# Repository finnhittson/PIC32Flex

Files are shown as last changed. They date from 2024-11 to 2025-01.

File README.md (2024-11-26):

# PIC32Flex 

PIC32Flex is a breakout board for the PIC32MX170F256B. This repo holds schematic revision information, how to fabricate this board for yourself, and examples on how to use the board. I designed this board for rapid prototyping, testing, and better wire management for projects and circuits that use the PIC32 as a microcontroller. Specifically, I made PIC32Flex for Stanford's ME218 mechatronics course sequence which exclusively uses the PIC32 as the microcontroller for all student projects. For this reason, it is wired to interface directly with the [MPLAB Snap](https://www.microchip.com/en-us/development-tool/pg164100) and the [CP2102 debugger](https://www.silabs.com/interface/usb-bridges/classic/device.cp2102?tab=specs).

<p align="center">
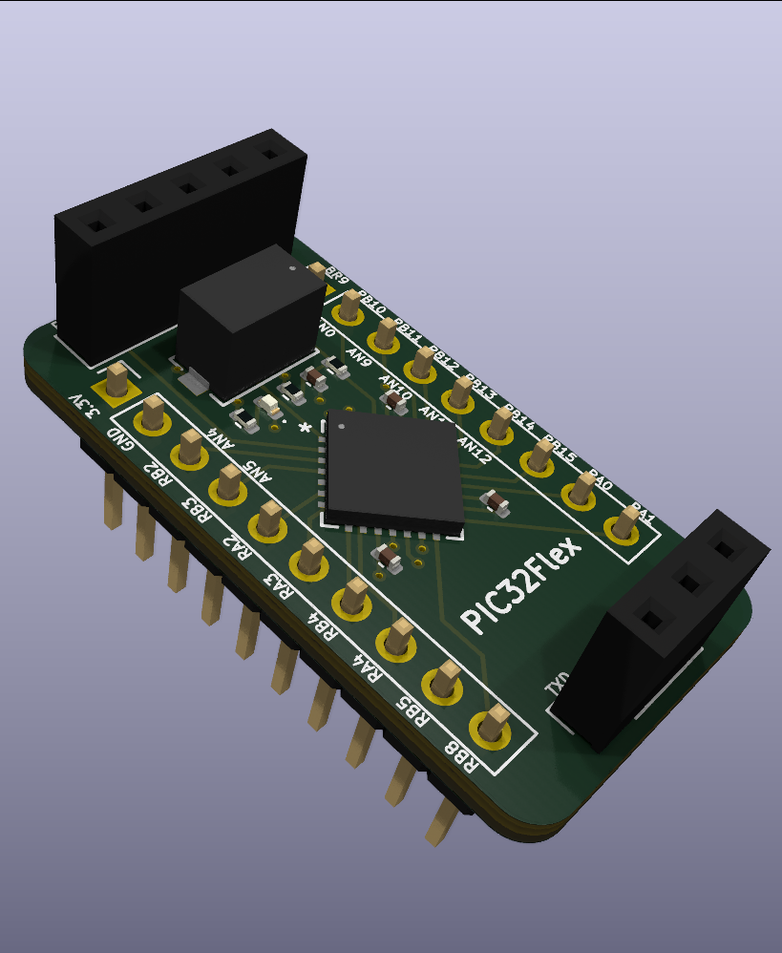
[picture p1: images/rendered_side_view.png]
  
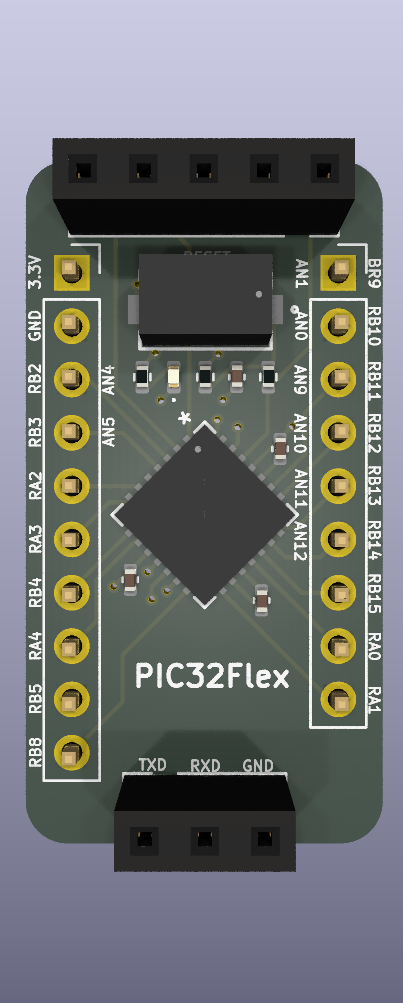
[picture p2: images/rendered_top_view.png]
  
</p>

## Download and Modification

To modify or view a revision of PIC32Flex, download any version of the board from the `hardware/` directory. All revisions were made using [KiCad 8.0](https://www.kicad.org/download/) which is a free PCB design software. Once downloaded, extract the file into the directory of your choice and open the `PIC32Flex.kicad_pro` file. This should open up a the KiCad start page where you can choose to view and then modify the schematic, PCB layout, and most other features related to the board. KiCad files are not backwards compatible so you may need to upgrade to KiCad 8.0 if you are working with an older version. If you download the most recent version and open the schematic editor, you will find the following.

<p align="center">
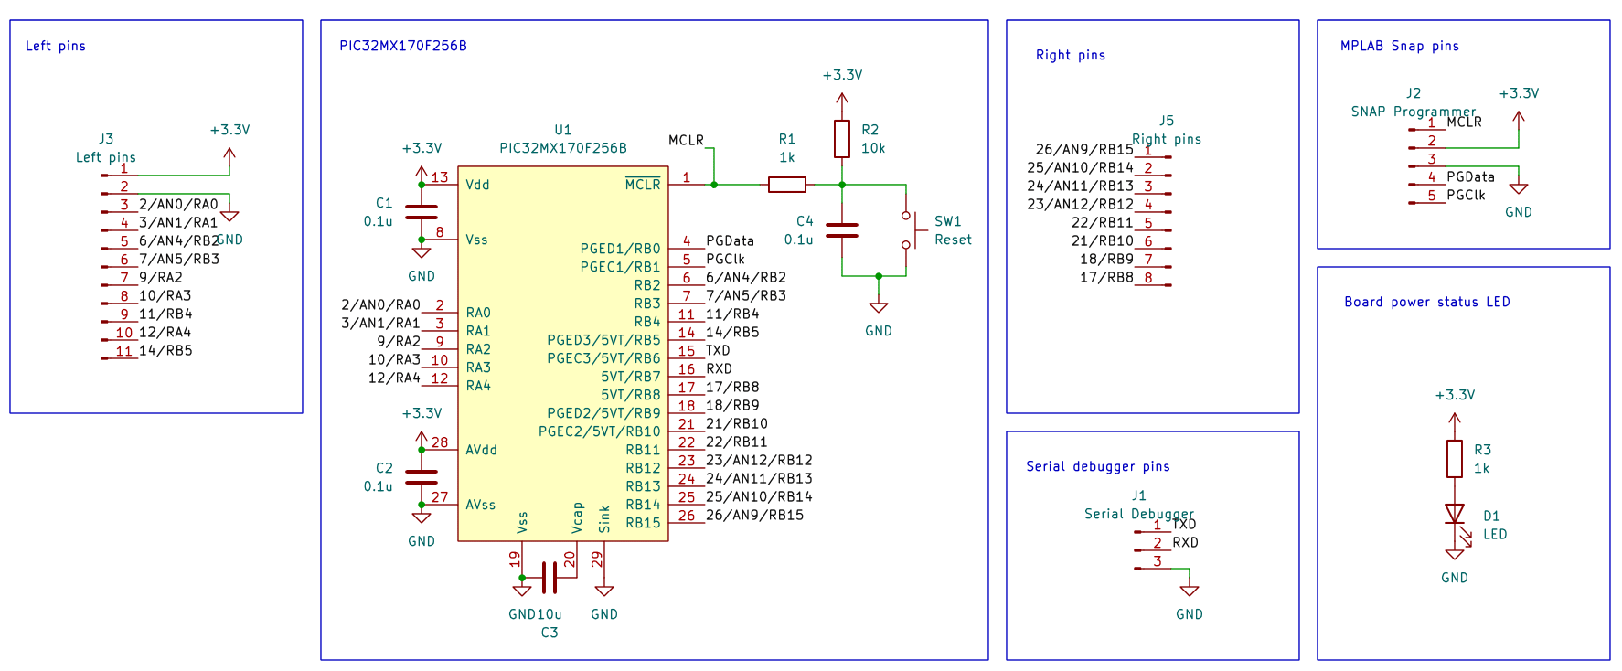
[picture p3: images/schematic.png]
  
</p>

Opening the PCB editor of the latest version should present the following PCB layout.

<p align="center">
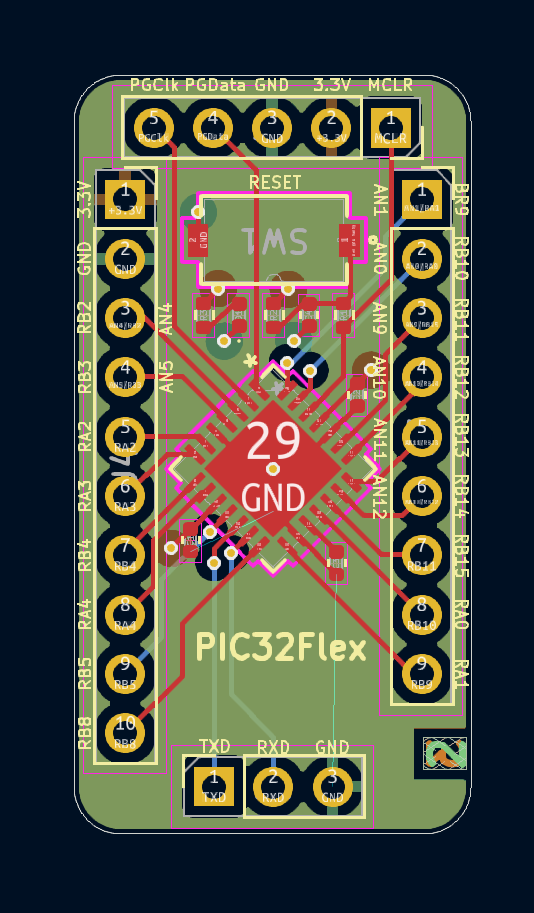
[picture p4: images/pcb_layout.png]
  
</p>

## Usage

To build this board for yourself you need to send the gerber files to a PCB manufacturer. Most used are [JLCPCN](https://jlcpcb.com/) and [PCBWay](https://www.pcbway.com/). After unzipping the downloaded board file, upload the `gerber.zip` file to a PCB manufacturer of your choice. It is recommended that the PIC32Flex is reflowed and not hand soldered. For this reason, be sure to include a stencil in your board purchase since they are not included by default. Board lead time is typically longer than a week. With the board ordered you will also need to order components for board population. Components can be ordered from [DigiKey](digikey.com) or [Mouser](mouser.com). With either of these suppliers you can upload the bill of materials file, `bom.csv`, and it will usually parse and place all the items in the cart. Below is a cost breakdown for the devices necessary for board population.

<div align="center">

| Qty | Reference | Value | Mfn | Mfn PN | Cost ($/device) |
|-----|---|---|---|---|---|
| 1 | C3 | 10u | Murata Electronics | GRM155R60J106ME05D | $0.10  |
| 3 | C1, C2, C4  | 0.1u | Murata Electronics | GRM155R71C104KA88J | $0.08  |
| 1 | D1 | LED | Inolux | IN-S42BTR | $0.28  |
| 1 | R2 | 10k | YAGEO | RC0402JR-0710KL | $0.10  |
| 2 | R1, R3 | 1k | YAGEO | RC0402JR-071KL | $0.10  |
| 1 | SW1 | Reset | C&K | PTS636SM50JSMTR LFS | $0.25  |
| 1 | U1 | PIC32MX170F256B | Microchip Technology | PIC32MX170F256B-I/ML | $4.86  |
| | | | | Total Device Cost | $6.03  |
| | | | | Total Board Cost w/ stencil | $9.11  |
| | | | | Total Costs | $15.14 |

</div>

This cost analysis does not include sales tax and shipping. These costs usually eclipse the cost of the board and components themselves, if you plan to only make a few.

## Contributing

Please download and change. Explore and learn. Please feel free to contact with questions, suggestions, and other projects you would like to see.

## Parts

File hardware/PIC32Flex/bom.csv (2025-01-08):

Qty | Reference | Value | Datasheet | Footprint | DNP | Mfn | Mfn PN | Supplier | Supplier PN
1 | C3 | 10u | https://search.murata.co.jp/Ceramy/image/img/A01X/G101/ENG/GRM155R60J106ME05-01A.pdf | Capacitor_SMD:C_0402_1005Metric |  | Murata Electronics | GRM155R60J106ME05D | DigiKey | 490-GRM155R60J106ME05DTR-ND
3 | C1,C2,C4 | 0.1u | https://search.murata.co.jp/Ceramy/image/img/A01X/G101/ENG/GRM155R71C104KA88-01.pdf | Capacitor_SMD:C_0402_1005Metric |  | Murata Electronics | GRM155R71C104KA88J | DigiKey | 490-6328-2-ND
1 | D1 | LED | https://www.inolux-corp.com/datasheet/SMDLED/Mono%20Color%20Top%20View/IN-S42BT%20Series_V1.0.pdf | LED_SMD:LED_0402_1005Metric |  | Inolux | IN-S42BTR | DigiKey | 1830-IN-S42BTR-ND
1 | J1 | Serial Debugger | ~ | Connector_PinSocket_2.54mm:PinSocket_1x03_P2.54mm_Vertical
1 | J2 | SNAP Programmer | ~ | Connector_PinSocket_2.54mm:PinSocket_1x05_P2.54mm_Vertical
1 | J3 | Conn_01x11_Pin | ~ | Connector_PinSocket_2.54mm:PinSocket_1x11_P2.54mm_Vertical
1 | J5 | Conn_01x08_Pin | ~ | Connector_PinHeader_2.54mm:PinHeader_1x08_P2.54mm_Vertical
1 | R2 | 10k | https://www.yageo.com/upload/media/product/products/datasheet/rchip/PYu-RC_Group_51_RoHS_L_12.pdf | Resistor_SMD:R_0402_1005Metric |  | YAGEO | RC0402JR-0710KL | DigiKey | 311-10KJRTR-ND
2 | R1,R3 | 1k | https://www.yageo.com/upload/media/product/products/datasheet/rchip/PYu-RC_Group_51_RoHS_L_12.pdf | Resistor_SMD:R_0402_1005Metric |  | YAGEO | RC0402JR-071KL | DigiKey | 311-1.0KJRTR-ND
1 | SW1 | Reset | https://www.ckswitches.com/media/2779/pts636.pdf | pic32_breakout:SW_PTS636_CNK |  | C&K | PTS636SM50JSMTR LFS | DigiKey | CKN12319-2-ND
1 | U1 | PIC32MX170F256B | https://www.digikey.com/en/models/4902616 | pic32_breakout:QFN28_6X6MC_MCH |  | Microchip Technology | PIC32MX170F256B-I/ML | DigiKey | PIC32MX170F256B-I/ML-ND

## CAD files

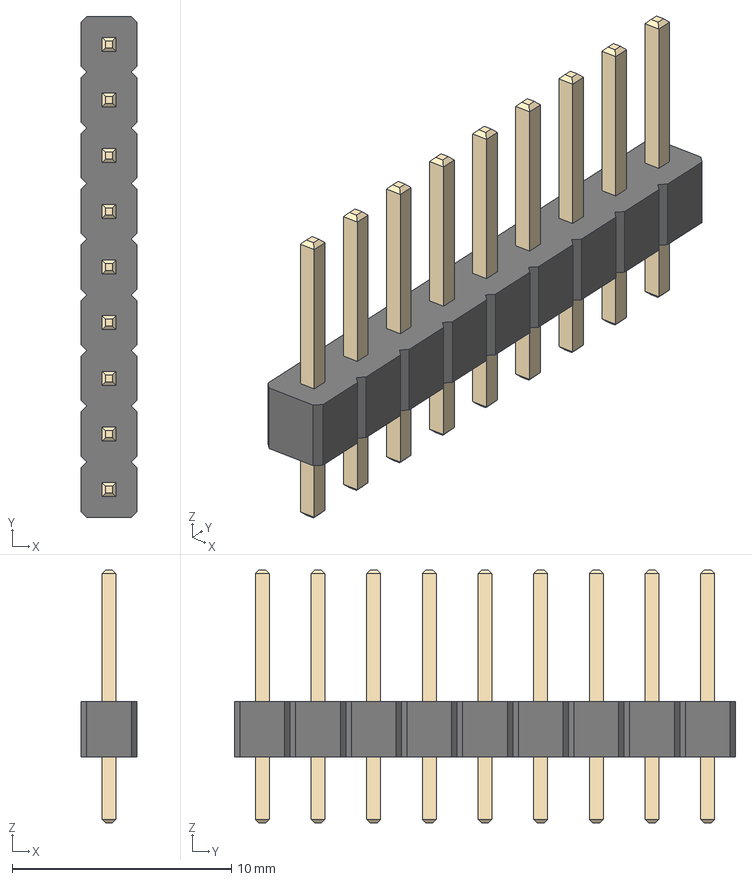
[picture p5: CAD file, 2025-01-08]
hardware/PIC32Flex/3d_models/PinHeader_1x09_P2.54mm_Vertical.step
2.54 x 22.9 x 11.5 mm

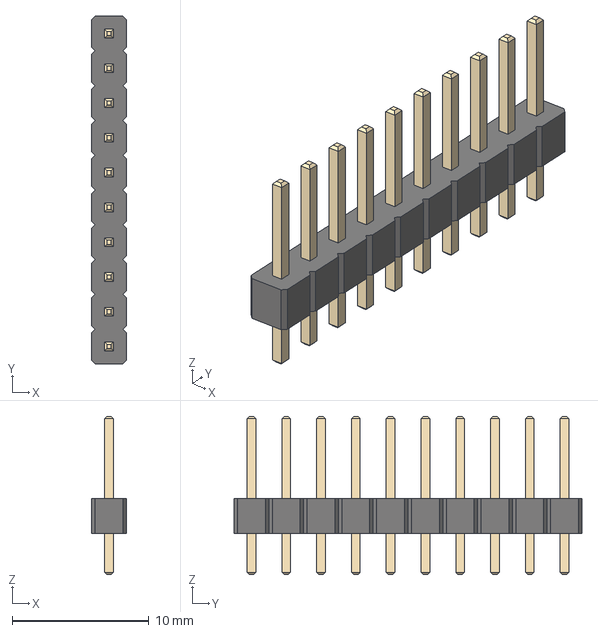
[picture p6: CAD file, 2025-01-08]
hardware/PIC32Flex/3d_models/PinHeader_1x10_P2.54mm_Vertical.step
2.54 x 25.4 x 11.5 mm

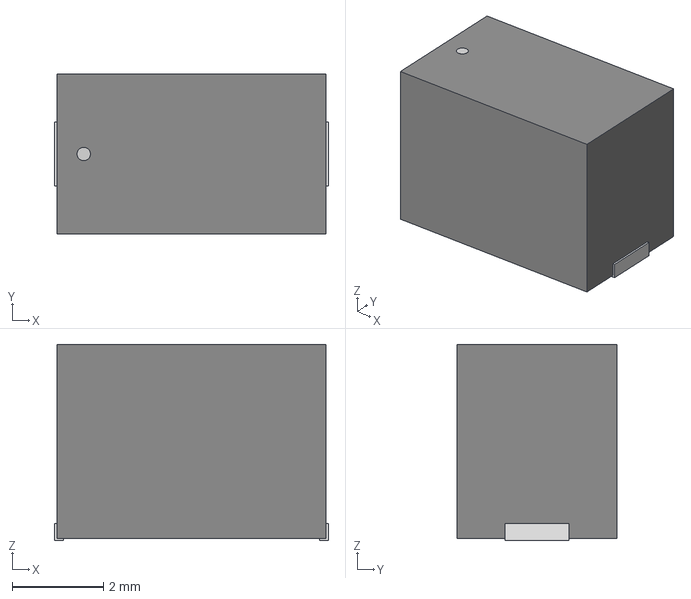
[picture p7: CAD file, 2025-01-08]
hardware/PIC32Flex/3d_models/SW_PTS636_CNK.step
5.99 x 3.51 x 4.29 mm

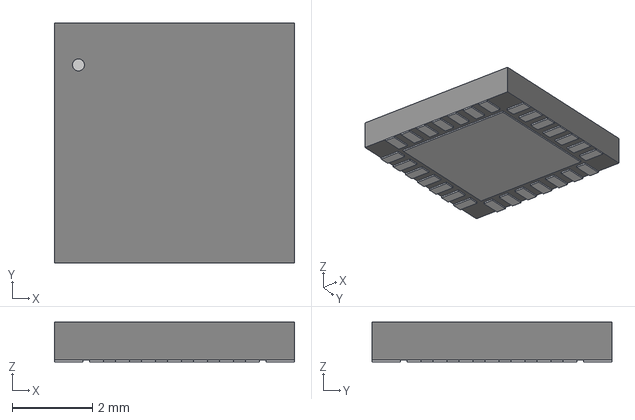
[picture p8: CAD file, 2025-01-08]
hardware/PIC32Flex/3d_models/QFN28_6X6MC_MCH.step
5.99 x 5.99 x 0.993 mm

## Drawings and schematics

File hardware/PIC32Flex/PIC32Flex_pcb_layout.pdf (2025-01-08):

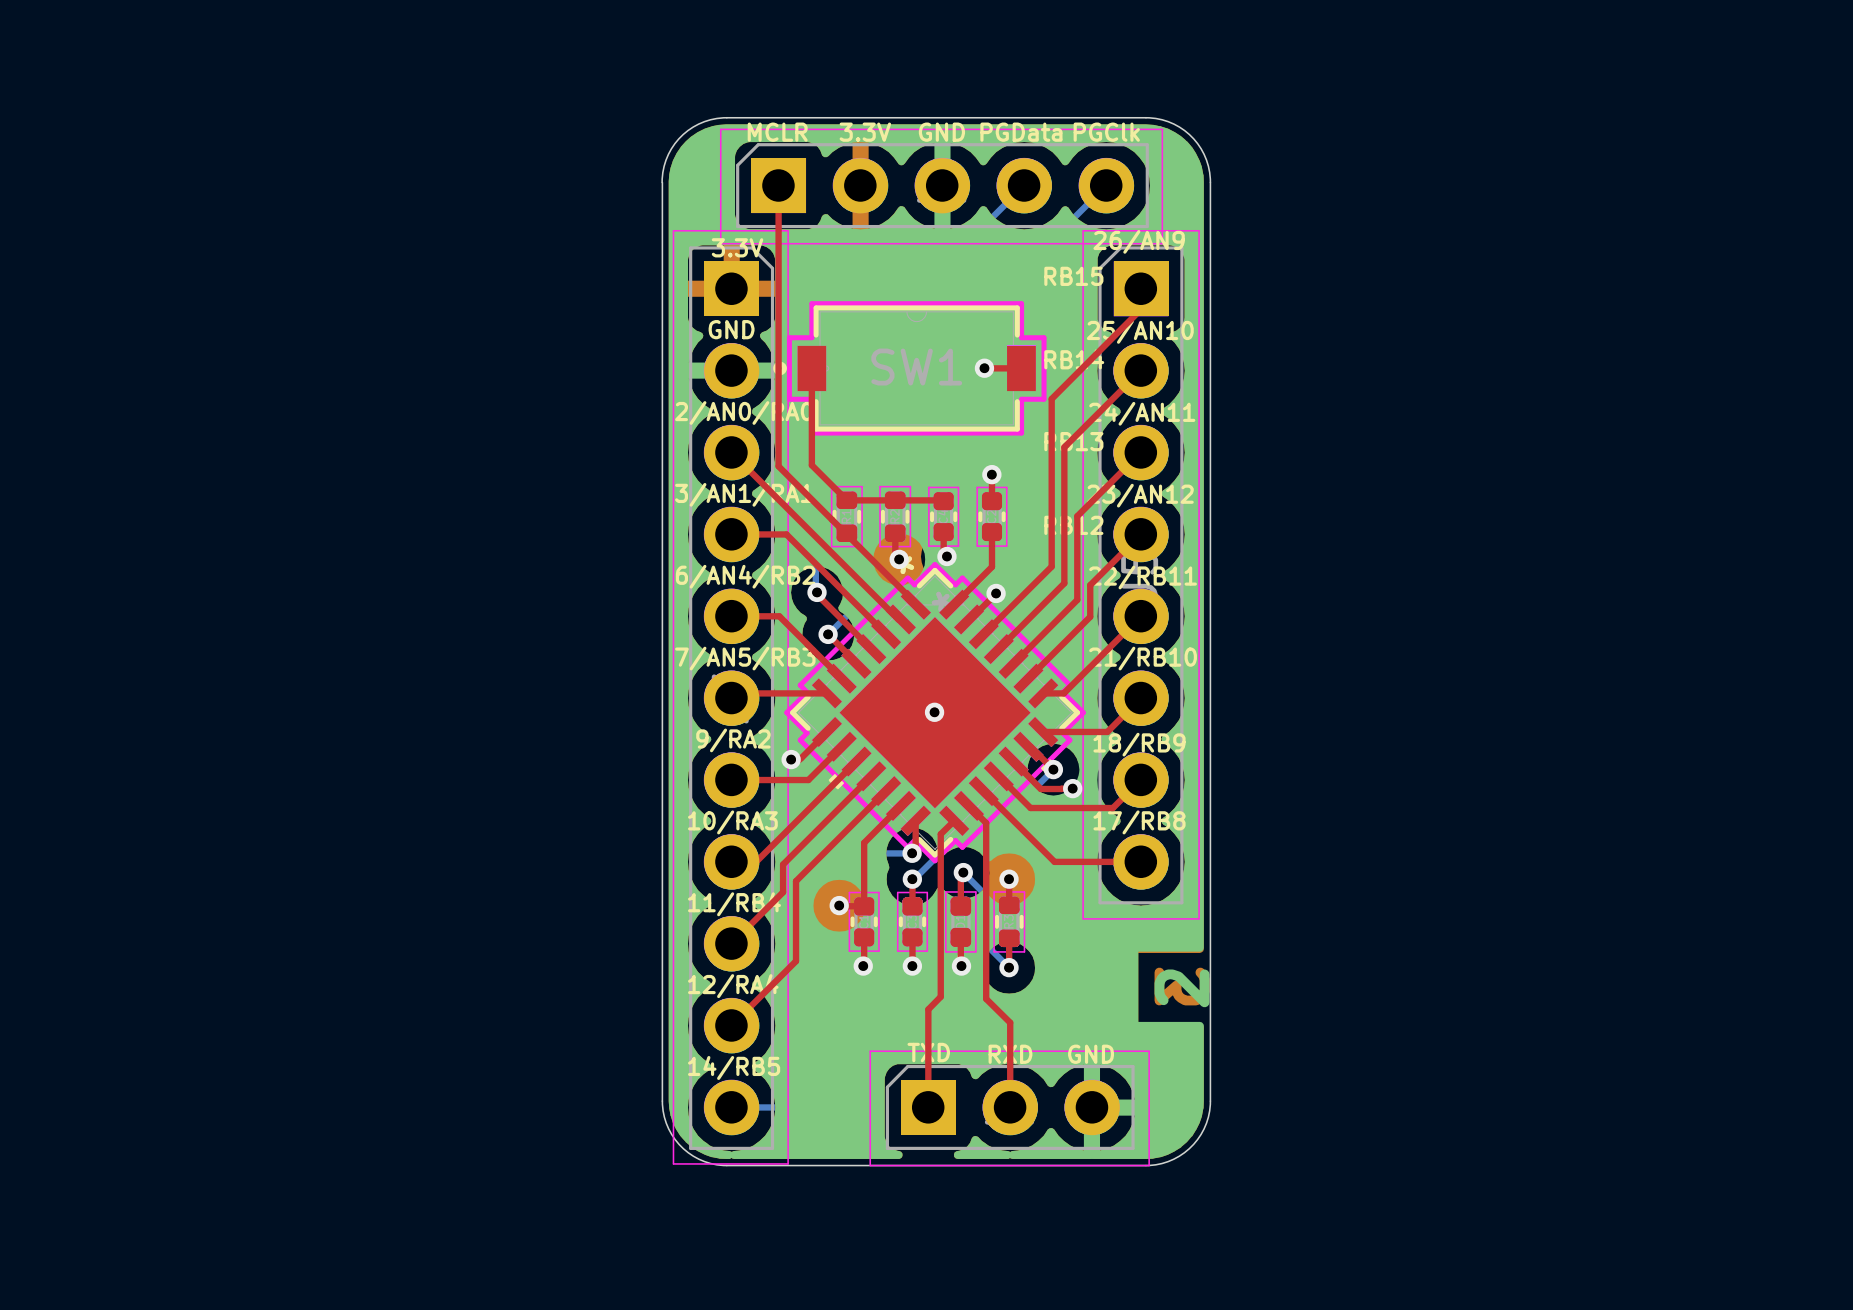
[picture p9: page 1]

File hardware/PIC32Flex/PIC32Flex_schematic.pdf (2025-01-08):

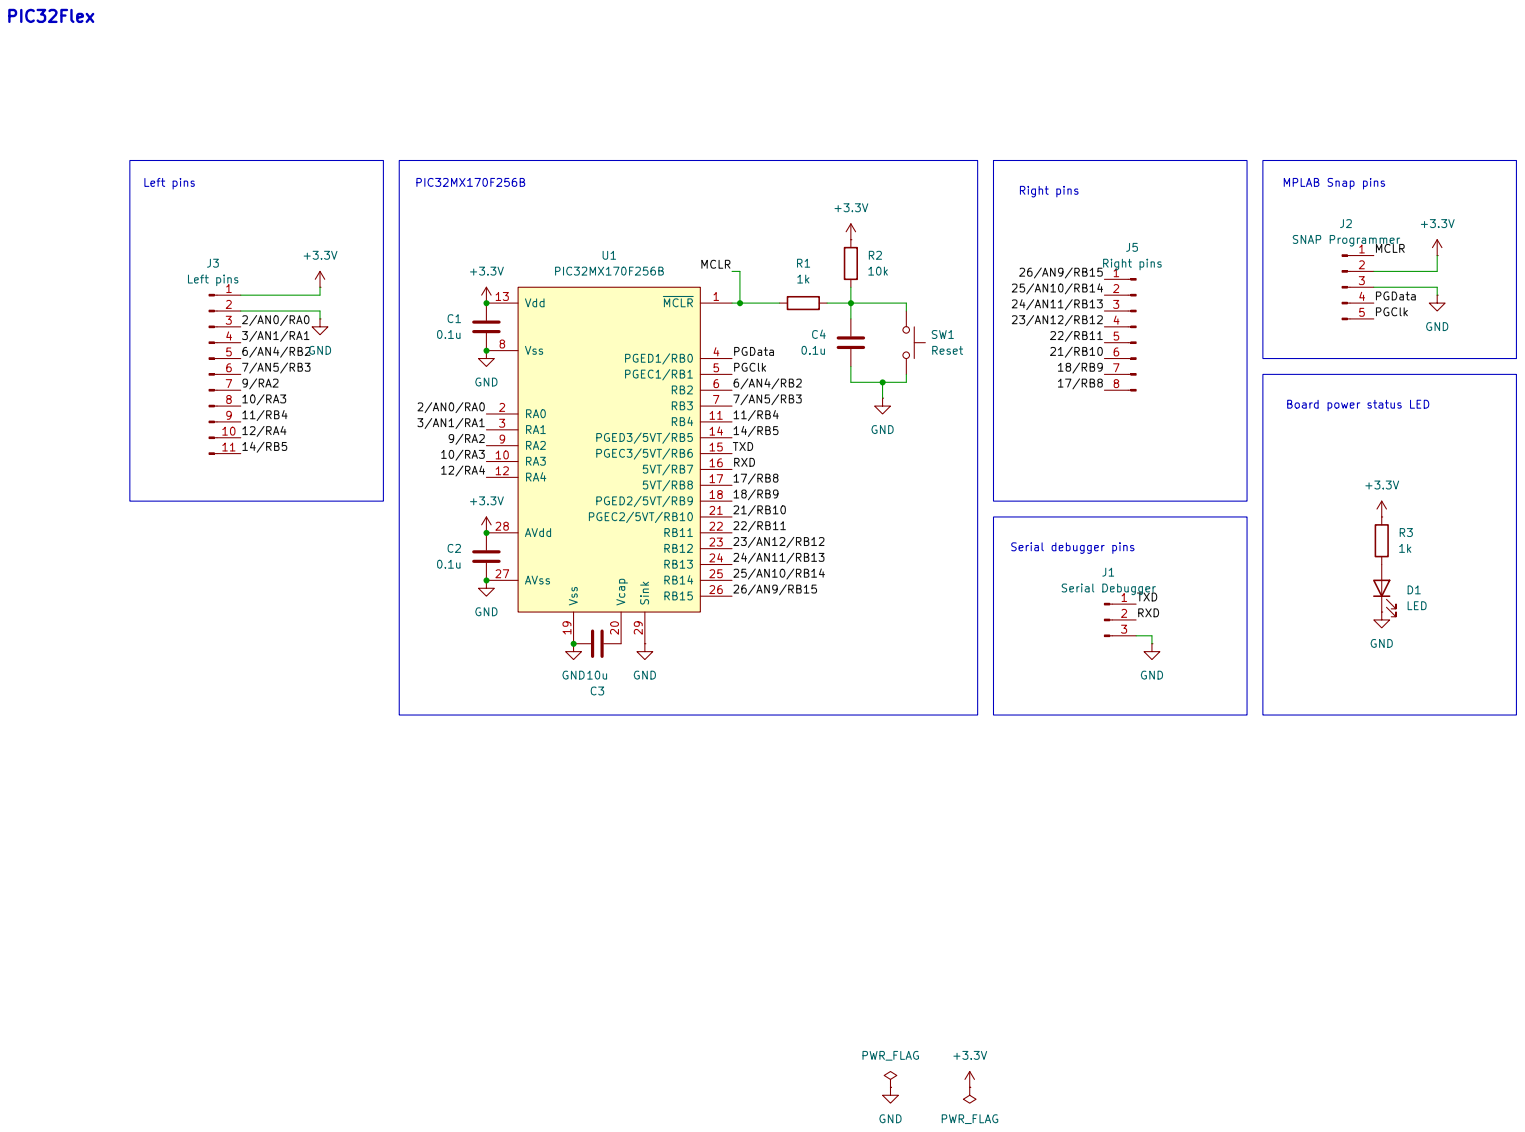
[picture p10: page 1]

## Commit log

2024-11-24 Add first iteration of pic32 breakout board
2024-11-25 Add BOM
2024-11-26 Add schematic
2024-11-26 Add pcb layout image
2024-11-26 Update board file
2025-01-08 Add current
    [PIC32Flex.kicad_sch, PinHeader_1x09_P2.54mm_Vertical.step, PinHeader_1x10_P2.54mm_Vertical.step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]
2025-01-10 Shrink board size and silk screen
    [PIC32Flex-B_Cu.gbr, PIC32Flex-B_Mask.gbr, PIC32Flex-B_Paste.gbr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]

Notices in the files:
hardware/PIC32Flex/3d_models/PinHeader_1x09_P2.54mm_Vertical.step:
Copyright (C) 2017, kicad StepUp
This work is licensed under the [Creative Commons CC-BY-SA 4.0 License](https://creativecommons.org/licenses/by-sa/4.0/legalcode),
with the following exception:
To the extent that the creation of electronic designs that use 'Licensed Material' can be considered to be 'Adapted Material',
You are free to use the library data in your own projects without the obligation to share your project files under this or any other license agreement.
